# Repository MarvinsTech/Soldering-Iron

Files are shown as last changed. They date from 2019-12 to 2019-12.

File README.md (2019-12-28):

# Soldering-Iron

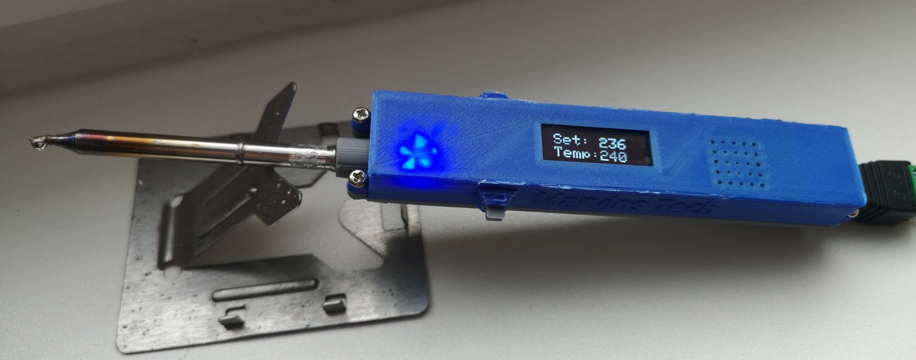
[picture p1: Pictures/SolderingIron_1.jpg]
Soldering Iron

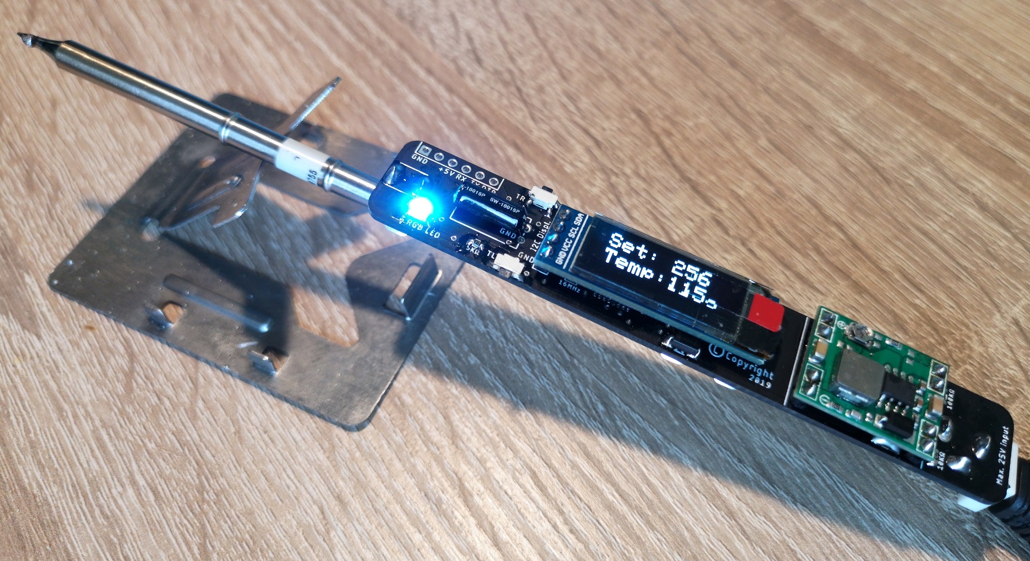
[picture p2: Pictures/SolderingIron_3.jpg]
Soldering Iron


### Required parts
* 1x [Soldering iron PCB](https://github.com/MarvinsTech/Soldering-Iron/tree/master/Eagle%20file/Soldering%20Iron%20V2/GerberFile.zip)
(To order the PCB, visit https://jlcpcb.com)
* 1x [ATmega328pAU](https://de.aliexpress.com/item/32900110997.html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,searchweb201602_4,searchweb201603_53)
* 1x [Female DC power jack](https://de.aliexpress.com/item/1000007253624.html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,searchweb201602_4,searchweb201603_53)
* 1x [16MHz SMD crystal](https://de.aliexpress.com/item/32451311354.html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,searchweb201602_4,searchweb201603_53)
* 1x [SS12 Schottky diode](https://de.aliexpress.com/item/32904408053.html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,searchweb201602_4,searchweb201603_53)
* 1x [2SC3356 R25 SOT-23](https://de.aliexpress.com/item/32895374766.html?spm=a2g0s.9042311.0.0.27424c4daI4iIC)
* 2x [1kΩ SMD Resistor](https://de.aliexpress.com/item/32865947306.html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,searchweb201602_4,searchweb201603_53)
* 5x [10kΩ SMD Resistor](https://de.aliexpress.com/item/32865947306.html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,searchweb201602_4,searchweb201603_53)
* 1x [1MΩ SMD Resistor](https://de.aliexpress.com/item/32865947306.html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,searchweb201602_4,searchweb201603_53)
* 1x [200kΩ SMD Resistor](https://de.aliexpress.com/item/32865947306.html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,searchweb201602_4,searchweb201603_53)
* 2x [5kΩ SMD Resistor](https://de.aliexpress.com/item/32865947306.html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,searchweb201602_4,searchweb201603_53)
* 1x [100KΩ SMD Resistor](https://de.aliexpress.com/item/32865947306.html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,searchweb201602_4,searchweb201603_53)
* 3x [71Ω SMD Resistor](https://de.aliexpress.com/item/32865947306.html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,searchweb201602_4,searchweb201603_53)
* 1x [2,2nF SMD Capacitor](https://de.aliexpress.com/item/33016966236.html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,searchweb201602_4,searchweb201603_53)
* 3x [100nF/0,1uF SMD Capacitor](https://de.aliexpress.com/item/33016966236.html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,searchweb201602_4,searchweb201603_53)
* 3x [PCB Fuse clip](https://de.aliexpress.com/item/32804593991.html?spm=a2g0s.9042311.0.0.27424c4daI4iIC)
* 1x [LM358 LM358DR SOP8](https://de.aliexpress.com/item/32418758151.html?spm=a2g0s.9042311.0.0.27424c4daI4iIC)
* 2x [90° SMD Side push button](https://de.aliexpress.com/item/32876437017.html?spm=a2g0s.9042311.0.0.27424c4daI4iIC)
* 1x [Vibrate sensor SW-18015P](https://de.aliexpress.com/item/32954698373.html?spm=a2g0s.9042311.0.0.27424c4dcR7Mjv)
* 1x [I2C OLED 128x32](https://de.aliexpress.com/item/32794583827.html?spm=a2g0s.9042311.0.0.27424c4dJZC5U3)
* 1x [IRF4905S MOSFET](https://de.aliexpress.com/item/32907696197.html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,searchweb201602_4,searchweb201603_53)
* 1x [RGB LED](https://de.aliexpress.com/item/32384196929.html?spm=a2g0s.9042311.0.0.27424c4dbM3enp)
* 1x USB B cable
* 1x [T12 tip](https://de.aliexpress.com/item/32964816255.html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,searchweb201602_4,searchweb201603_53)
* 1x [Buck converter 22 * 17 * 5mm](https://de.aliexpress.com/item/32901415443.html?spm=a2g0s.9042311.0.0.27424c4dPg1aoU)
* 1x [FTDI module](https://de.aliexpress.com/item/32826575637.html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,searchweb201602_4,searchweb201603_53)
* 1x Heatsink 14 * 14,5 * 4mm
* 4x M2 screws and nuts

### Hints
Note that the two points of the GND bridge are connected with solder!
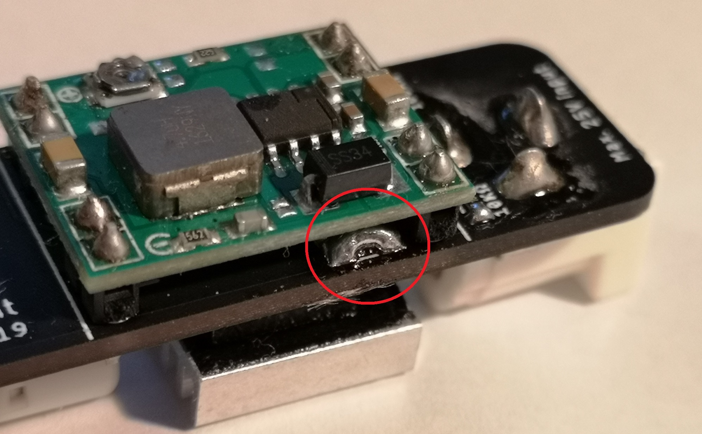
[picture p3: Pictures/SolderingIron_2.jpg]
Soldering iron


### Completely soldered example

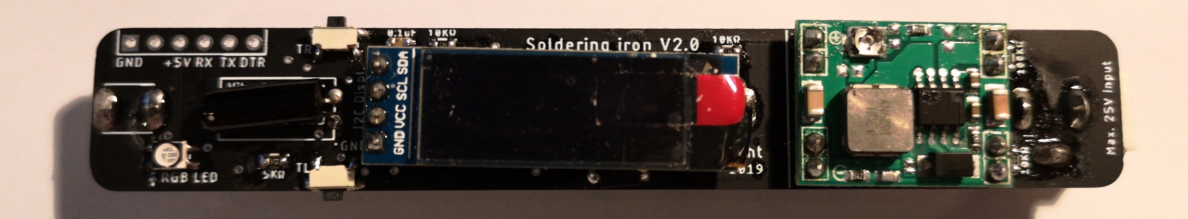
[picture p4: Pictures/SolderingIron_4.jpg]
Soldering iron

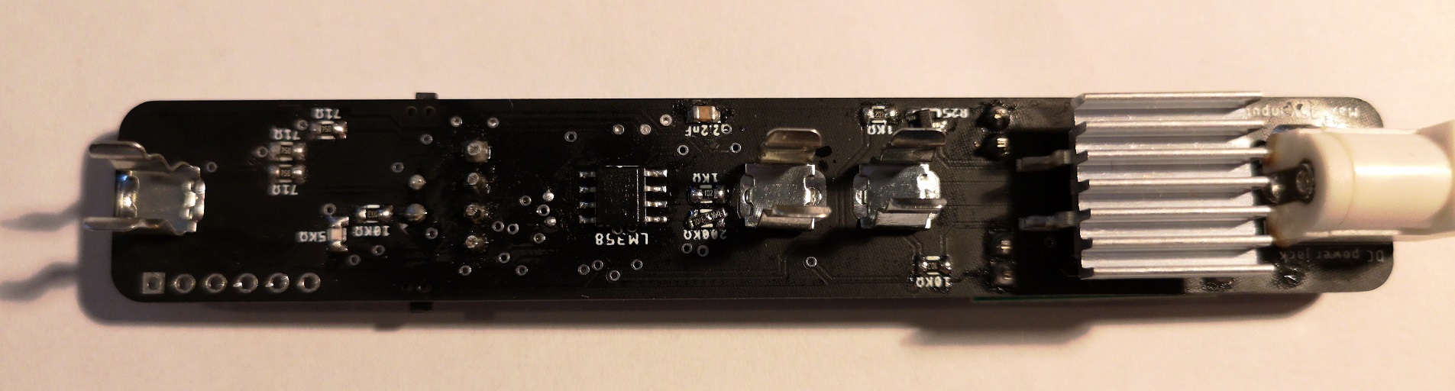
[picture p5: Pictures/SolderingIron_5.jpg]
Soldering iron


### Installing the bootloader on ATmega328
Almost all newly purchased ATmega328 microcontrollers lack the boot loader, so we have to install it ourselves. For this we need an Arduino that is connected as shown in the picture (Make sure that all components on the PCB except the display are soldered!). After the ATmega328 is connected to the Arduino via jumper cables, we have to install OptiLoader on the Arduino and see if it does not display an error message in the serial monitor. If no error message appears, the jumper cables can be unsoldered from the ATmega328.

https://github.com/WestfW/OptiLoader

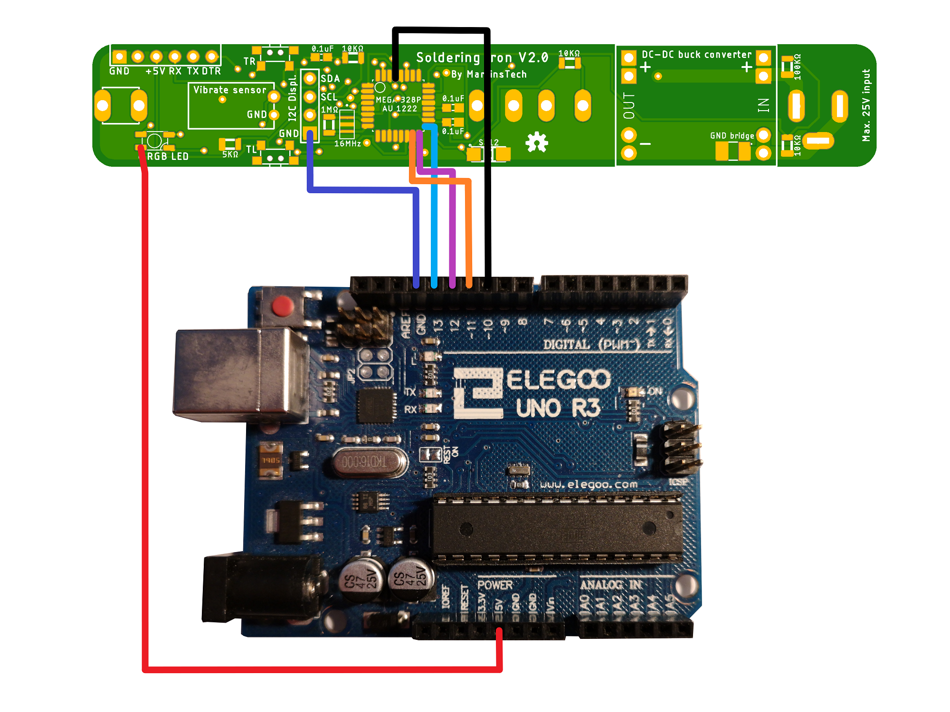
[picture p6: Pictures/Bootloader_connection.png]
Bootloader connection


### Load the program onto ATmega328
Before we load the program onto the ATmega328, we first have to implement the FTDI module in the Arduino IDE. To do this, follow the step-by-step instructions below.

* Open the Arduino IDE.
* Open the File > Preferences menu item.
* Enter the following URL in Additional Boards Manager URLs:
`https://mcudude.github.io/MiniCore/package_MCUdude_MiniCore_index.json`
* Open the Tools > Board > Boards Manager... menu item.
* Wait for the platform indexes to finish downloading.
* Scroll down until you see the MiniCore entry and click on it.
* Click Install.

Next we select the ATmega328 board from Tools, connect the FTDI module to the computer and upload the program to the PCB via the FTDI interface.

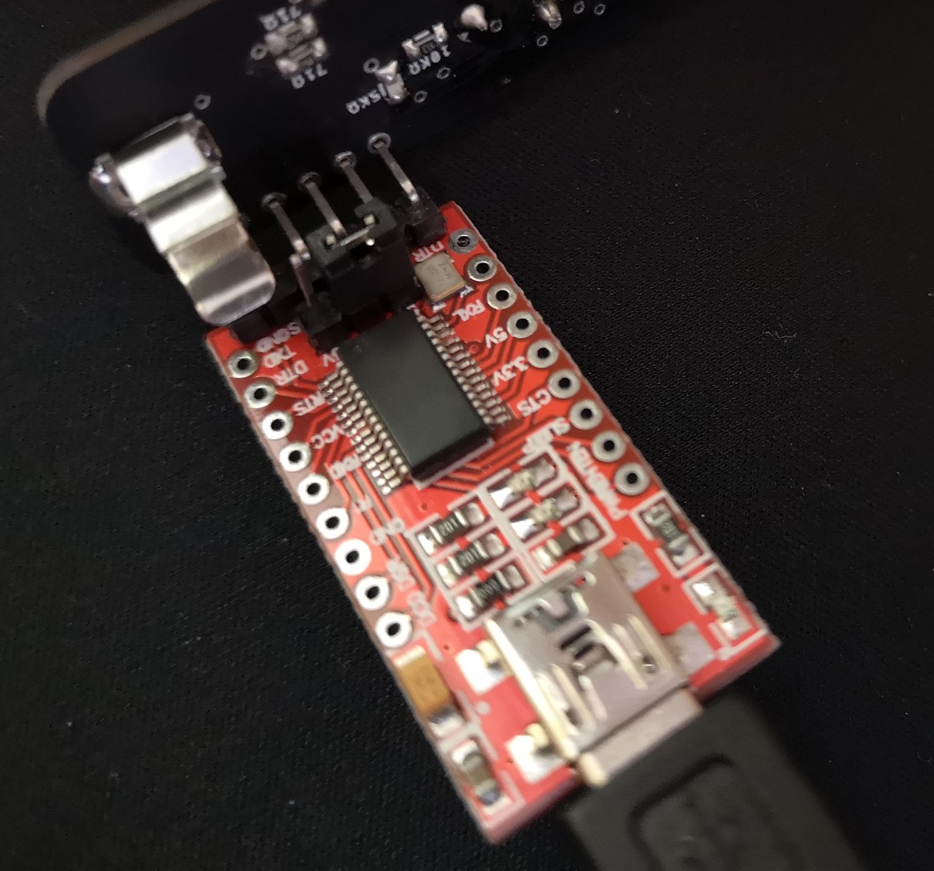
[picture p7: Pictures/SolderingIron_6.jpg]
FTDI programmer


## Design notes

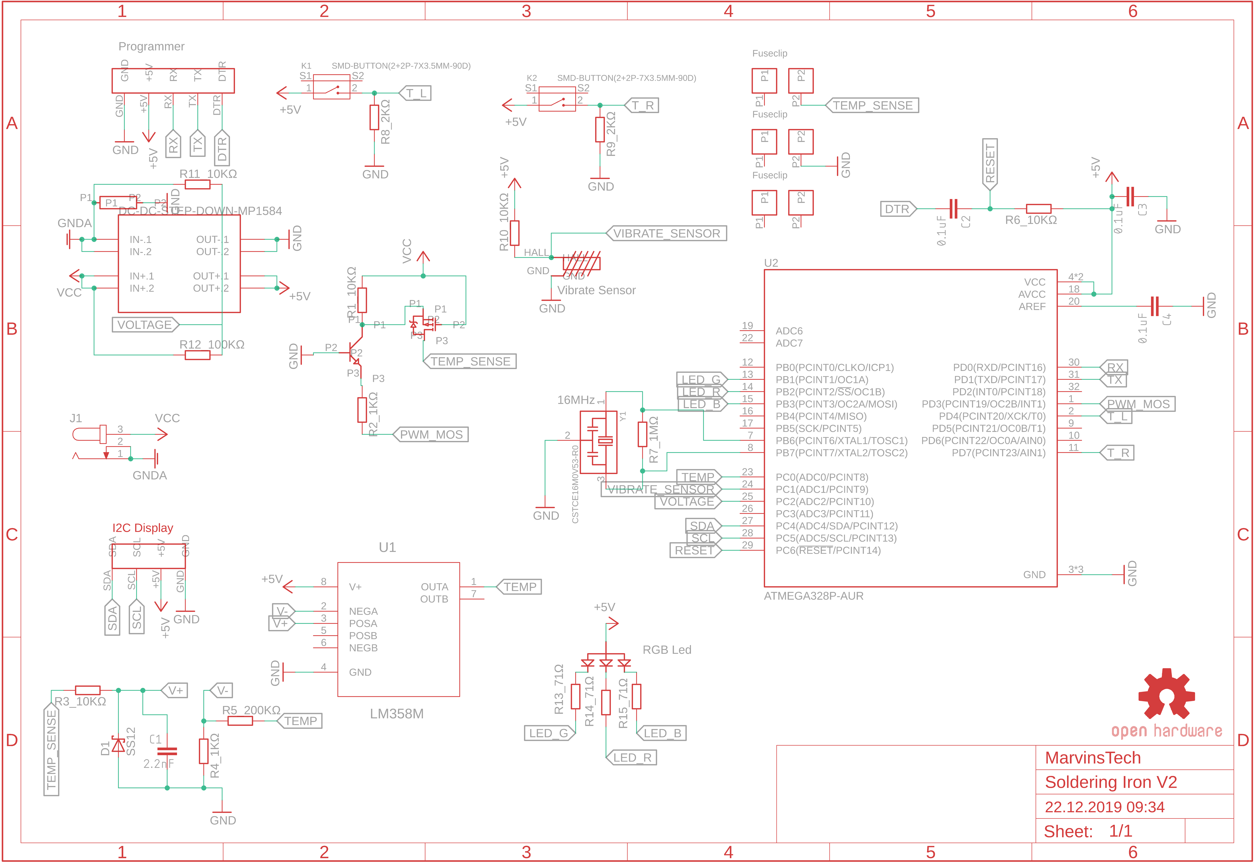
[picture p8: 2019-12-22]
Eagle file/Soldering Iron V2/Schematic.png

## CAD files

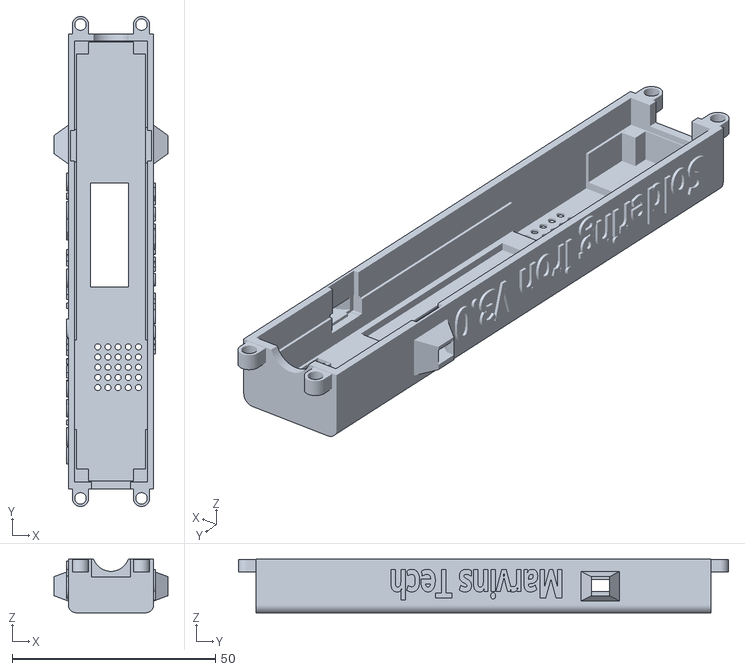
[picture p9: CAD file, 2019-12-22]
3D case/1x Soldering Iron V2.0 top.stl
28.0 x 120.5 x 13.2

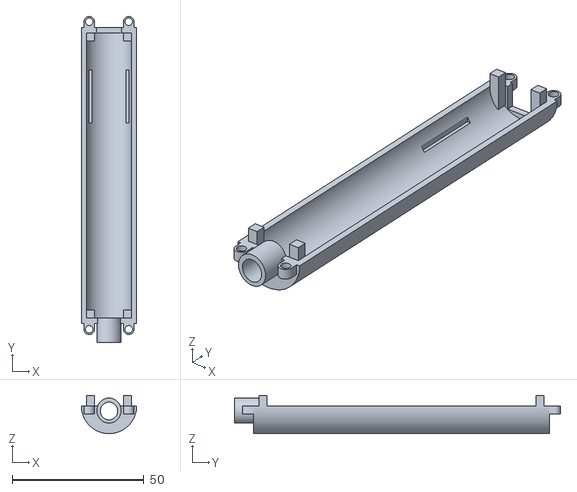
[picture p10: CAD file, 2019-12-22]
3D case/1x Soldering Iron V2.0 bottom.stl
21.0 x 123.5 x 14.5

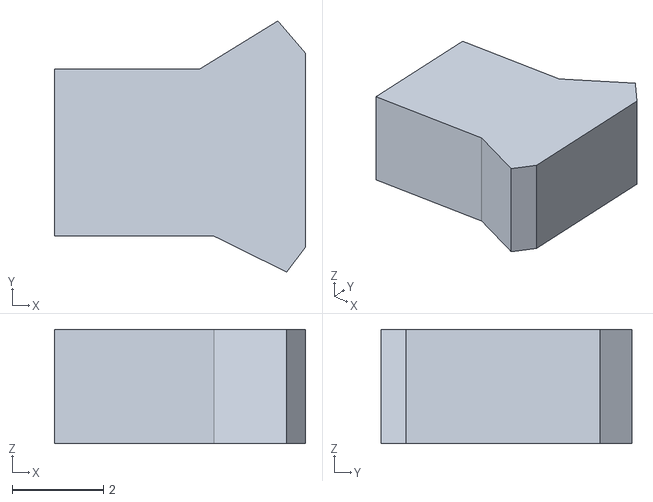
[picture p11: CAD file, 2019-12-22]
3D case/2x Soldering Iron V2.0 button.stl
5.50 x 5.50 x 2.50

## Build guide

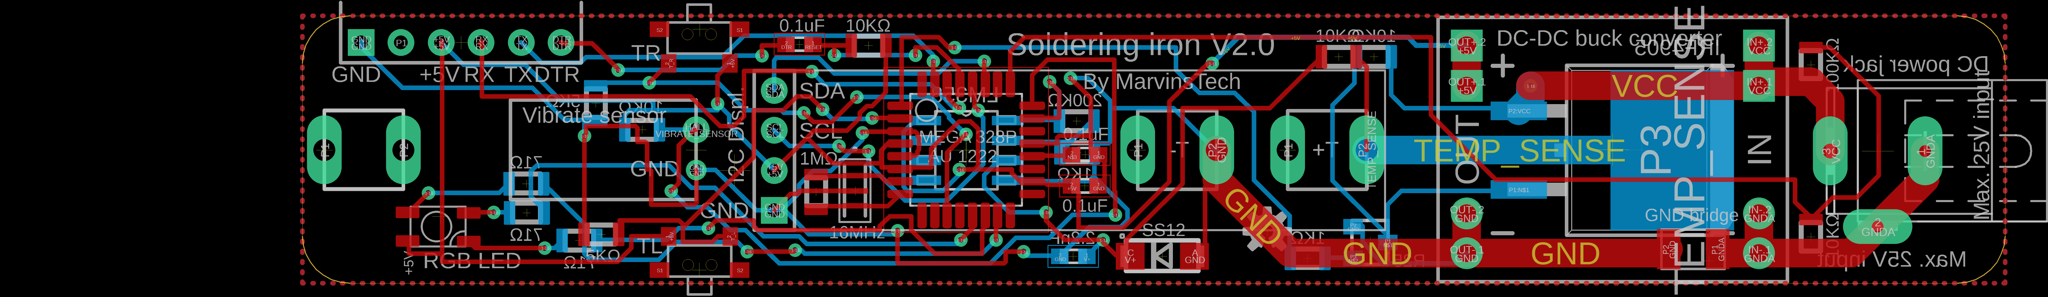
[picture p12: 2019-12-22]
Eagle file/Soldering Iron V2/SolderingIronV2.png

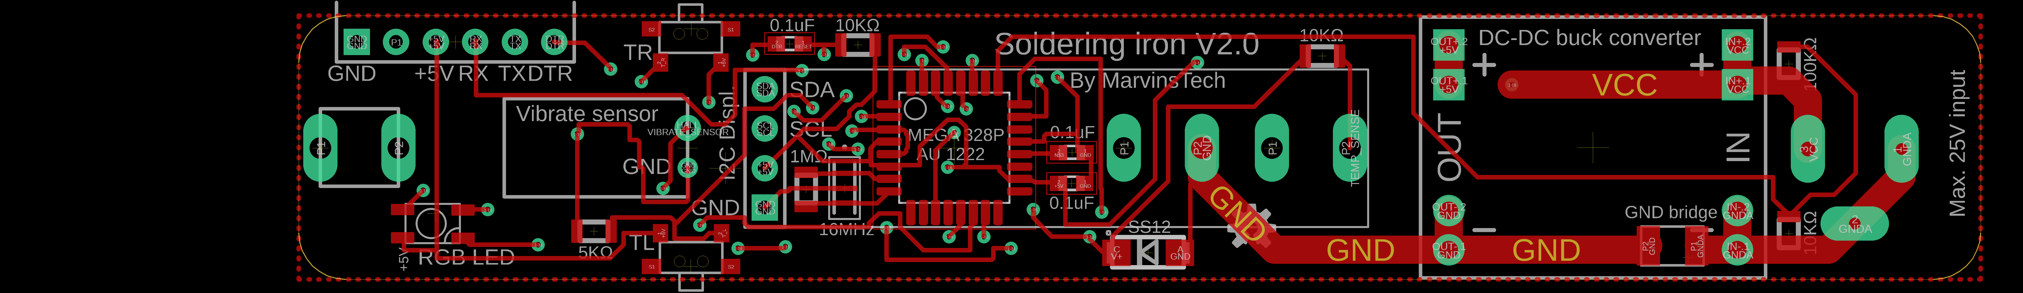
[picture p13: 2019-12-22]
Eagle file/Soldering Iron V2/SolderingIronV2_top.png

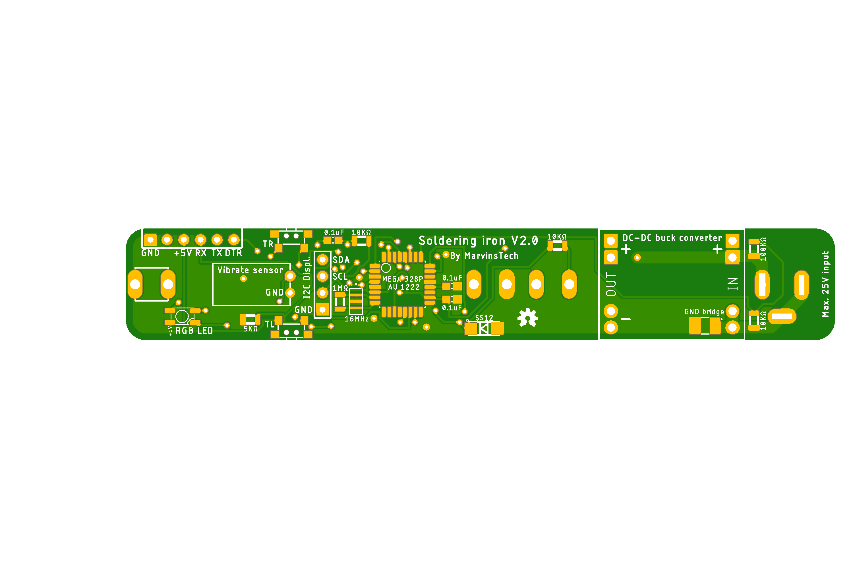
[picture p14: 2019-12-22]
Eagle file/Soldering Iron V2/Soldering Iron V2.png

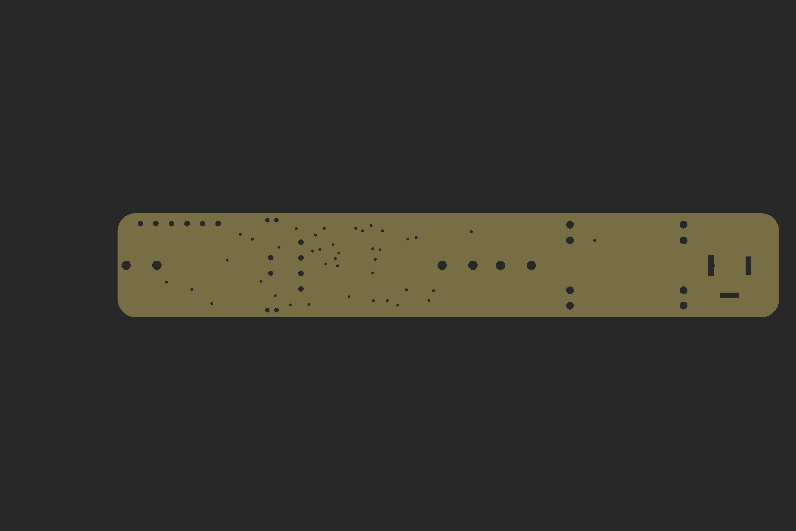
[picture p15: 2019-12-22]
Eagle file/Soldering Iron V2/Soldering Iron V2_drills.png

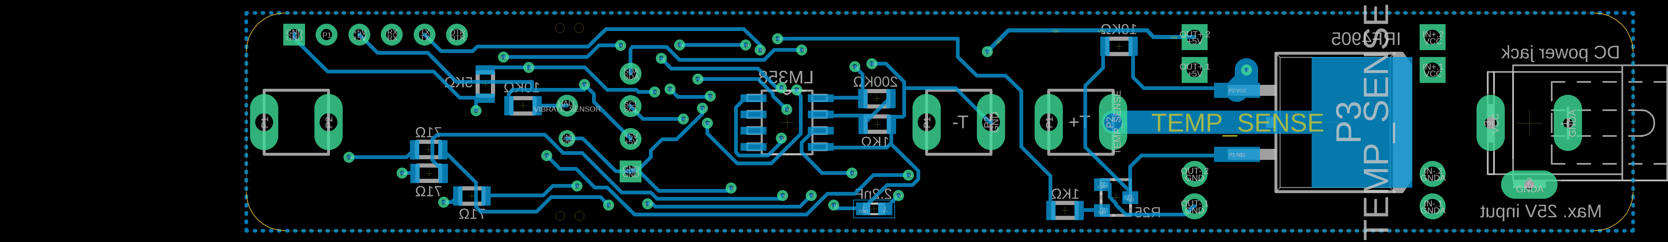
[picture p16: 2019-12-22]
Eagle file/Soldering Iron V2/SolderingIronV2_bottom.png

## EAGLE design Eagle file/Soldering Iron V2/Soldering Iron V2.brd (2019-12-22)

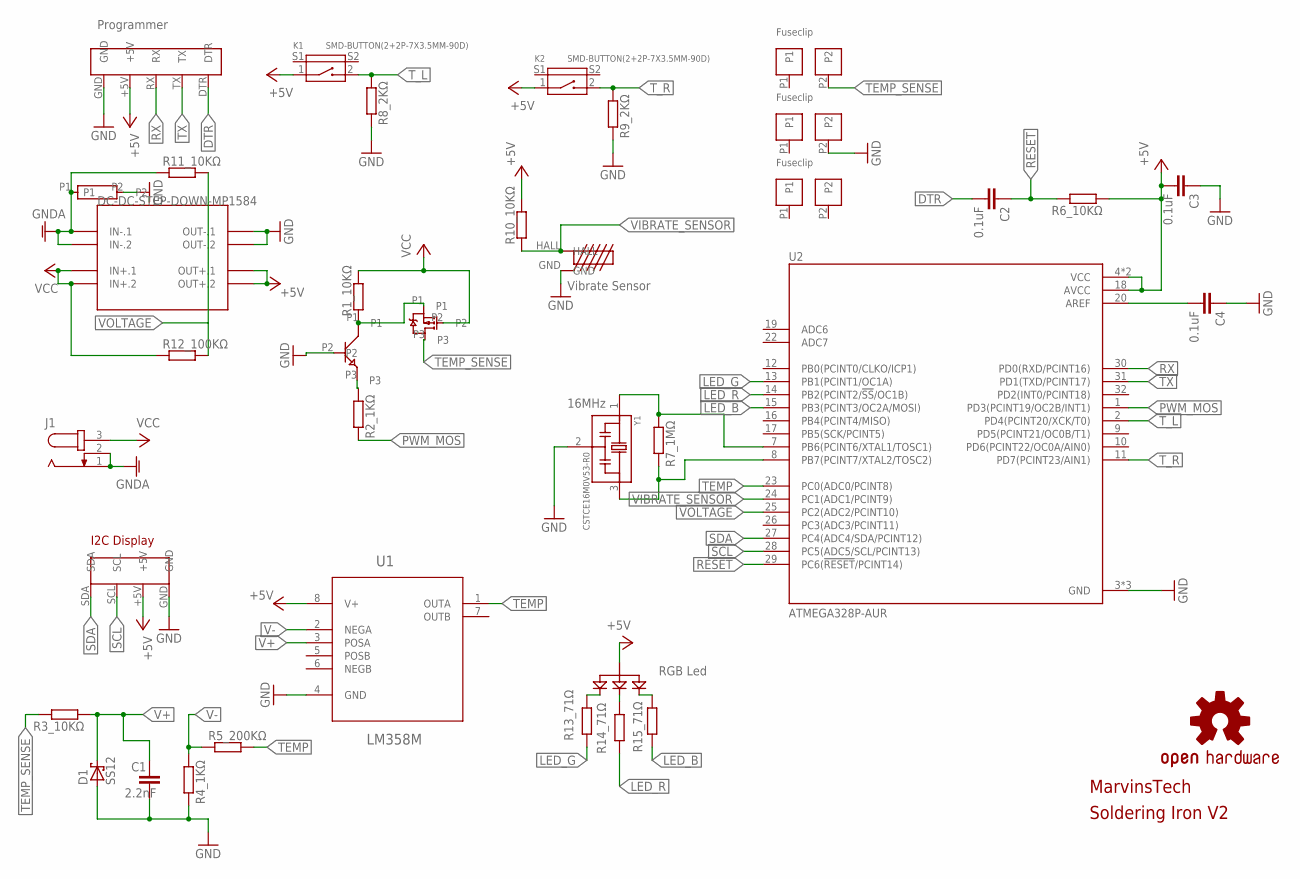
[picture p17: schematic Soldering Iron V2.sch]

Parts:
C1: 2.2nF; 0603
C2, C3, C4: 0.1uF; 0603
D1: SS12; DO214AC
J1: JACK-PLUG0; SPC4077
K1, K2: SMD-BUTTON(2+2P-7X3.5MM-90D); SW4-SMD-7.0X3.5X3.5MM-90D
R1_10KΩ, R2_1KΩ, R3_10KΩ, R4_1KΩ, R5_200KΩ, R6_10KΩ, R7_1MΩ, R8_2KΩ, R9_2KΩ, R10_10KΩ, R11_10KΩ, R12_100KΩ, R13_71Ω, R14_71Ω, R15_71Ω: SMK
U1: LM358M; SOIC127P620X175-8N
U2: ATMEGA328P-AUR; QFP80P900X900X120-32N
U$1: DC-DC-STEP-DOWN-MP1584
U$2: IRF4905STRLPBF; D2PAK-5
U$3: 2SC3356NPNBJT; TO236
U$4: I2C_DISPLAY
U$5: VIBRATESENSOR
U$6, U$7, U$8: FUSECLIPS; FUSECLIP
U$9: SHUNT_RESISTOR1; RESISTOR1
U$10: RGBLED
U$11: PROGRAMMER
U$15: OSHW-LOGOS; OSHW-LOGO-S
Y1: CSTCE16M0V53-R0; OSC_CSTCE16M0V53-R0

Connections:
+5V: C3.2, K1.1, K2.1, R6_10KΩ.2, R10_10KΩ.1, U1.8 (V+), U2.4 (VCC), U2.6 (VCC), U2.18 (AVCC), U$1.OUT+.1, U$1.OUT+.2, U$4.+5V, U$10.+5V, U$11.+5V
DTR: C2.2, U$11.DTR
GND: C1.2, C3.1, C4.1, D1.A, R4_1KΩ.1, R8_2KΩ.1, R9_2KΩ.1, U1.4 (GND), U2.3 (GND), U2.5 (GND), U2.21 (GND), U$1.OUT-.1, U$1.OUT-.2, U$3.P2, U$4.GND, U$5.GND, U$7.P2, U$9.P2, U$11.GND, Y1.2
GNDA: J1.1, J1.2, R11_10KΩ.2, U$1.IN-.1, U$1.IN-.2, U$9.P1
LED_B: R15_71Ω.1, U2.15 (PB3(PCINT3/OC2A/MOSI))
LED_G: R13_71Ω.2, U2.13 (PB1(PCINT1/OC1A))
LED_R: R14_71Ω.2, U2.14 (PB2(PCINT2/!SS!/OC1B))
unnamed: R1_10KΩ.2, U$2.P1, U$3.P1
unnamed: R2_1KΩ.2, U$3.P3
unnamed: C4.2, U2.20 (AREF)
unnamed: R7_1MΩ.2, U2.7 (PB6(PCINT6/XTAL1/TOSC1)), Y1.1
unnamed: R7_1MΩ.1, U2.8 (PB7(PCINT7/XTAL2/TOSC2)), Y1.3
unnamed: R14_71Ω.1, U$10.P2
unnamed: R13_71Ω.1, U$10.P3
unnamed: R15_71Ω.2, U$10.P1
PWM_MOS: R2_1KΩ.1, U2.1 (PD3(PCINT19/OC2B/INT1))
RESET: C2.1, R6_10KΩ.1, U2.29 (PC6(!RESET!/PCINT14))
RX: U2.30 (PD0(RXD/PCINT16)), U$11.RX
SCL: U2.28 (PC5(ADC5/SCL/PCINT13)), U$4.SCL
SDA: U2.27 (PC4(ADC4/SDA/PCINT12)), U$4.SDA
TEMP: R5_200KΩ.1, U1.1 (OUTA), U2.23 (PC0(ADC0/PCINT8))
TEMP_SENSE: R3_10KΩ.1, U$2.P3, U$6.P2
TX: U2.31 (PD1(TXD/PCINT17)), U$11.TX
T_L: K1.2, R8_2KΩ.2, U2.2 (PD4(PCINT20/XCK/T0))
T_R: K2.2, R9_2KΩ.2, U2.11 (PD7(PCINT23/AIN1))
V+: C1.1, D1.C, R3_10KΩ.2, U1.3 (POSA)
V-: R4_1KΩ.2, R5_200KΩ.2, U1.2 (NEGA)
VCC: J1.3, R1_10KΩ.1, R12_100KΩ.2, U$1.IN+.1, U$1.IN+.2, U$2.P2
VIBRATE_SENSOR: R10_10KΩ.2, U2.24 (PC1(ADC1/PCINT9)), U$5.HALL
VOLTAGE: R11_10KΩ.1, R12_100KΩ.1, U2.25 (PC2(ADC2/PCINT10))

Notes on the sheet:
16MHz
Vibrate Sensor
Programmer
RGB Led
MarvinsTech
Soldering Iron V2

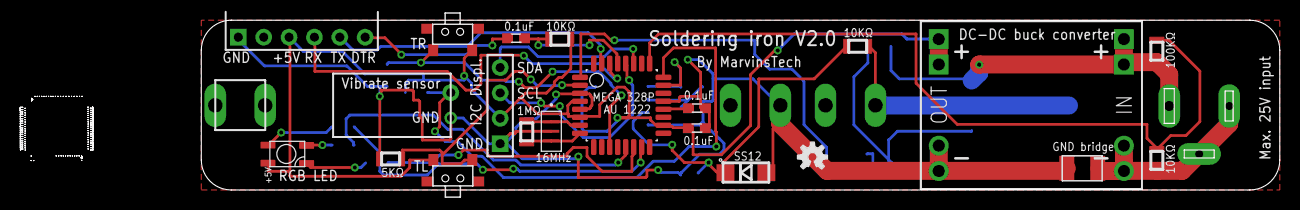
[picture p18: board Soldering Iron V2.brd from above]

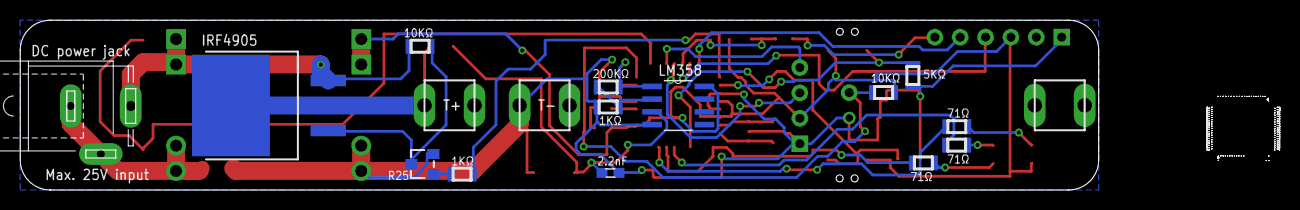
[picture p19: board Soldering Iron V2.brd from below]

Board: 2 copper layers, 108.0 x 17.0 mm, 38 parts (14 on the bottom side), 30 nets.

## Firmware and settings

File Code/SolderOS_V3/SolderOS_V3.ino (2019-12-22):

/*SolderOS V3.0 | Changed on 22/12/2019 by MarvinsTech
*/

static const unsigned char PROGMEM  press_logo[] =
{
  B00000000, B00000000, B00000000, B00000000, B00000000, B00000000, B00000000, B00000000, B00000000, B00000000, B00000000, B00000000, B00000000, B00000000, B00000000, B00000000,
  B11111001, B11110011, B11100111, B10001111, B10000000, B00000000, B00000000, B00000000, B00000000, B00000000, B00000000, B00000000, B00000000, B00000000, B00000000, B00000000,
  B10000000, B01000010, B00100100, B01000010, B00000000, B00000000, B00000000, B00000000, B00000000, B00000000, B00000000, B00000000, B00000000, B00000000, B00000000, B00000000,
  B10000000, B01000010, B00100100, B01000010, B00000000, B00000000, B00000000, B00000000, B00000000, B00000000, B00000000, B00000000, B00000000, B00000000, B00000000, B00000000,
  B11111000, B01000011, B11100111, B10000010, B00111111, B11111111, B11111111, B11111111, B11111100, B00000000, B00000000, B00000000, B00000000, B00000000, B00000000, B00000000,
  B00001000, B01000010, B00100101, B00000010, B00000000, B00000000, B00000000, B00000000, B00000010, B00000000, B00000000, B00000000, B00000000, B00000000, B00000000, B00000000,
  B00001000, B01000010, B00100100, B10000010, B00000000, B00000000, B00000000, B00000000, B00000001, B00000000, B00000000, B00000000, B00000000, B00000000, B00000000, B00000000,
  B11111000, B01000010, B00100100, B01000010, B00000000, B00000000, B00000000, B00000000, B00000000, B10000000, B00000000, B00000000, B00000000, B00000000, B00000000, B00000000,
  B00000000, B00000000, B00000000, B00000000, B00000000, B00000000, B00000000, B00000000, B00000000, B00000000, B00000000, B00000000, B00000000, B00000000, B00000000, B00000000,
  B00000000, B00000000, B00000000, B00000000, B00000000, B00000000, B00000000, B00000000, B00000000, B11000000, B11000000, B00000000, B00000000, B00000000, B00000000, B00000000,
  B00000000, B00000000, B00000000, B00000000, B00000000, B00000000, B00000000, B00000000, B00000000, B01100001, B10000000, B00000000, B00000000, B00000000, B00000000, B00000000,
  B00000000, B00000000, B00000000, B00000000, B00000000, B00000000, B00000000, B00000000, B00000000, B00111111, B00000000, B00000000, B00000000, B00000000, B00000000, B00000000,
  B00000000, B00000000, B00000000, B00000000, B00000000, B00000000, B00000000, B00000000, B00000000, B00001100, B00000000, B00000000, B00000000, B00000000, B00000000, B00000000,
  B00000000, B00000000, B00000000, B00000000, B00000000, B00000000, B00000000, B00000000, B00000000, B00000000, B00000000, B00000000, B00000000, B00000000, B00000000, B00000000,
  B00000000, B00000000, B00000000, B00000000, B00000000, B00000000, B00000000, B00000000, B00000000, B00111110, B00000000, B00000000, B00000000, B00000000, B00011111, B00000000,
  B00000000, B00000000, B00000000, B00000000, B00000000, B00000000, B00000000, B00000000, B11111111, B11111111, B11111111, B11111111, B11111111, B11111111, B11111111, B11100000,
  B00000000, B00000000, B00111111, B11111111, B11111111, B11111111, B11111111, B11111111, B11111111, B11111111, B11111111, B11111111, B11111111, B11111111, B11111111, B11111111,
  B00000000, B00000001, B11111111, B11111111, B11111111, B11111111, B11111111, B11111111, B11111111, B11111111, B11111111, B11111111, B11111111, B11111111, B11111111, B11111111,
  B00000000, B00000000, B00111111, B11111111, B11111111, B11111111, B11111111, B11111111, B11111111, B11111111, B11111111, B11111111, B11111111, B11111111, B11111111, B11100000,
  B00000000, B00000000, B00000000, B00000000, B00000000, B00000000, B00000000, B00000000, B11111111, B11111111, B11111111, B11111111, B11111111, B11111111, B11111111, B11100000,
  B00000000, B00000000, B00000000, B00000000, B00000000, B00000000, B00000000, B00000000, B00000000, B00111110, B00000000, B00000000, B00000000, B00000000, B00000000, B00000000,
  B00000000, B00000000, B00000000, B00000000, B00000000, B00000000, B00000000, B00000000, B00000000, B00000000, B00000000, B00000000, B00000000, B00000000, B00000000, B00000000,
  B00000000, B00000000, B00000000, B00000000, B00000000, B00000000, B00000000, B00000000, B00000000, B00000000, B00000000, B00000000, B00000000, B00000000, B00000000, B00000000,
  B00000000, B00000000, B00000000, B00000000, B00000000, B00000000, B00000000, B00000000, B00000000, B00000000, B00000000, B00000000, B00000000, B00000000, B00000000, B00000000,
  B00000000, B00000000, B00000000, B00000000, B00000000, B00000000, B00000000, B00000000, B00000000, B00000000, B00000000, B00000000, B00000000, B00000000, B00000000, B00000000,
  B00000000, B00000000, B00000000, B00000000, B00000000, B00000000, B00000000, B00000000, B00000000, B00000000, B00000000, B00000000, B00000000, B00000000, B00000000, B00000000,
  B00000000, B00000000, B00000000, B00000000, B00000000, B00000000, B00000000, B00000000, B00000000, B00000000, B00000000, B00000000, B00000000, B00000000, B00000000, B00000000,
  B00000000, B00000000, B00000000, B00000000, B00000000, B00000000, B00000000, B00000000, B00000000, B00000000, B00000000, B00000000, B00000000, B00000000, B00000000, B00000000,
  B00000000, B00000000, B00000000, B00000000, B00000000, B00000000, B00000000, B00000000, B00000000, B00000000, B00000000, B00000000, B00000000, B00000000, B00000000, B00000000,
  B00000000, B00000000, B00000000, B00000000, B00000000, B00000000, B00000000, B00000000, B00000000, B00000000, B00000000, B00000000, B00000000, B00000000, B00000000, B00000000,
  B00000000, B00000000, B00000000, B00000000, B00000000, B00000000, B00000000, B00000000, B00000000, B00000000, B00000000, B00000000, B00000000, B00000000, B00000000, B00000000,
  B00000000, B00000000, B00000000, B00000000, B00000000, B00000000, B00000000, B00000000, B00000000, B00000000, B00000000, B00000000, B00000000, B00000000, B00000000, B00000000
};

//Bytes for the sleep mode icon toggle with CONFIG icon
static const unsigned char PROGMEM no_press_logo[] =
{
  B00000000, B00000000, B00000000, B00000000, B00000000, B00000000, B00000000, B00000000, B00000000, B00000000, B00000000, B00000000, B00000000, B00000000, B00000000, B00000000,
  B00000000, B00000000, B00000000, B00000000, B00000000, B00000000, B00000000, B00000000, B00000000, B00000000, B00000000, B00000000, B00000000, B00000000, B00000000, B00000000,
  B00000000, B00000000, B00000000, B00000000, B00000000, B00000000, B00000000, B00000000, B00000000, B00000000, B00000000, B00000000, B00000000, B00000000, B00000000, B00000000,
  B00000000, B00000000, B00000000, B00000000, B00000000, B00000000, B00000000, B00000000, B00000000, B00000000, B00000000, B00000000, B00000000, B00000000, B00000000, B00000000,
  B00000000, B00000000, B00000000, B00000000, B00000000, B00000000, B00000000, B00000000, B00000000, B00000000, B00000000, B00000000, B00000000, B00000000, B00000000, B00000000,
  B00000000, B00000000, B00000000, B00000000, B00000000, B00000000, B00000000, B00000000, B00000000, B00000000, B00000000, B00000000, B00000000, B00000000, B00000000, B00000000,
  B00000000, B00000000, B00000000, B00000000, B00000000, B00000000, B00000000, B00000000, B00000000, B00000000, B00000000, B00000000, B00000000, B00000000, B00000000, B00000000,
  B00000000, B00000000, B00000000, B00000000, B00000000, B00000000, B00000000, B00000000, B00000000, B00000000, B00000000, B00000000, B00000000, B00000000, B00000000, B00000000,
  B00000000, B00000000, B00000000, B00000000, B00000000, B00000000, B00000000, B00000000, B00000000, B00000000, B00000000, B00000000, B00000000, B00000000, B00000000, B00000000,
  B00000000, B00000000, B00000000, B00000000, B00000000, B00000000, B00000000, B00000000, B00000000, B00000000, B00000000, B00000000, B00000000, B00000000, B00000000, B00000000,
  B00000000, B00000000, B00000000, B00000000, B00000000, B00000000, B00000000, B00000000, B00000000, B00000000, B00000000, B00000000, B00000000, B00000000, B00000000, B00000000,
  B00000000, B00000000, B00000000, B00000000, B00000000, B00000000, B00000000, B00000000, B00000000, B00000000, B00000000, B00000000, B00000000, B00000000, B00000000, B00000000,
  B00000000, B00000000, B00000000, B00000000, B00000000, B00000000, B00000000, B00000000, B00000000, B00000000, B00000000, B00000000, B00000000, B00000000, B00000000, B00000000,
  B00000000, B00000000, B00000000, B00000000, B00000000, B00000000, B00000000, B00000000, B00000000, B00000000, B00000000, B00000000, B00000000, B00000000, B00000000, B00000000,
  B00000000, B00000000, B00000000, B00000000, B00000000, B00000000, B00000000, B00000000, B00000000, B00111110, B00000000, B00000000, B00000000, B00000000, B00011111, B00000000,
  B00000000, B00000000, B00000000, B00000000, B00000000, B00000000, B00000000, B00000000, B11111111, B11111111, B11111111, B11111111, B11111111, B11111111, B11111111, B11100000,
  B00000000, B00000000, B00111111, B11111111, B11111111, B11111111, B11111111, B11111111, B11111111, B11111111, B11111111, B11111111, B11111111, B11111111, B11111111, B11111111,
  B00000000, B00000001, B11111111, B11111111, B11111111, B11111111, B11111111, B11111111, B11111111, B11111111, B11111111, B11111111, B11111111, B11111111, B11111111, B11111111,
  B00000000, B00000000, B00111111, B11111111, B11111111, B11111111, B11111111, B11111111, B11111111, B11111111, B11111111, B11111111, B11111111, B11111111, B11111111, B11100000,
  B00000000, B00000000, B00000000, B00000000, B00000000, B00000000, B00000000, B00000000, B11111111, B11111111, B11111111, B11111111, B11111111, B11111111, B11111111, B11100000,
  B00000000, B00000000, B00000000, B00000000, B00000000, B00000000, B00000000, B00000000, B00000000, B00111110, B00000000, B00000000, B00000000, B00000000, B00000000, B00000000,
  B00000000, B00000000, B00000000, B00000000, B00000000, B00000000, B00000000, B00000000, B00000000, B00000000, B00000000, B00000000, B00000000, B00000000, B00000000, B00000000,
  B00000000, B00000000, B00000000, B00000000, B00000000, B00000000, B00000000, B00000000, B00000000, B00001100, B00000000, B00000000, B00000000, B00000000, B00000000, B00000000,
  B00000000, B00000000, B00000000, B00000000, B00000000, B00000000, B00000000, B00000000, B00000000, B00111111, B00000000, B00000000, B00000000, B00000000, B00000000, B00000000,
  B11111001, B11110010, B00100111, B11001001, B11110000, B00000000, B00000000, B00000000, B00000000, B01100001, B10000000, B00000000, B00000000, B00000000, B00000000, B00000000,
  B10000001, B00010011, B00100100, B00001001, B00000000, B00000000, B00000000, B00000000, B00000000, B11000000, B11000000, B00000000, B00000000, B00000000, B00000000, B00000000,
  B10000001, B00010011, B00100111, B10001001, B00000000, B00000000, B00000000, B00000000, B00000000, B10000000, B00000000, B00000000, B00000000, B00000000, B00000000, B00000000,
  B10000001, B00010010, B10100100, B00001001, B00000000, B00000000, B00000000, B00000000, B00000001, B00000000, B00000000, B00000000, B00000000, B00000000, B00000000, B00000000,
  B10000001, B00010010, B01100100, B00001001, B00110011, B11111111, B11111111, B11111111, B11111110, B00000000, B00000000, B00000000, B00000000, B00000000, B00000000, B00000000,
  B10000001, B00010010, B01100100, B00001001, B00010000, B00000000, B00000000, B00000000, B00000000, B00000000, B00000000, B00000000, B00000000, B00000000, B00000000, B00000000,
  B11111001, B11110010, B00100100, B00001001, B11110000, B00000000, B00000000, B00000000, B00000000, B00000000, B00000000, B00000000, B00000000, B00000000, B00000000, B00000000,
  B00000000, B00000000, B00000000, B00000000, B00000000, B00000000, B00000000, B00000000, B00000000, B00000000, B00000000, B00000000, B00000000, B00000000, B00000000, B00000000
};

String Version = "Version 3.0";
float min_temp = 150;                            //This is the minimum temperature that the iron could get
float max_temp = 500;                            //This is the maximum temperature that the iron could get
float Delay = 200;                               //Refresh rate. This is the time in ms the loop runs (PID+temperature read)
int   setpoint = 250;                            //Temperature setpoint initial value
int   sleeptime = 3;                             //Wait to enter into sleep mode. Time in minutes
int   max_sleeptime = 10;                        //This is the maximum sleep time you could set the iron
int   sleeptime_adress = 2;
int   setpoint_adress_low = 3;
int   setpoint_adress_mid = 4;
int   setpoint_adress_high = 5;

float Voltage = 0.0;
int val = 0;

#include "max6675.h"              //Downlaod it here: https://github.com/adafruit/MAX6675-library
#include <SPI.h>
#include <Wire.h>
#include <Adafruit_GFX.h>         //Downlaod it here: https://github.com/adafruit/Adafruit-GFX-Library
#include <Adafruit_SSD1306.h>     //Downlaod it here: https://github.com/adafruit/Adafruit_SSD1306
#include <FastPID.h>              //Dwonload it here: https://github.com/mike-matera/FastPID
#include <EEPROM.h>
#include <math.h>
#include "pins.h"

#define OLED_RESET 8
Adafruit_SSD1306 display(OLED_RESET);
#define NUMFLAKES 5
#define XPOS 0
#define YPOS 1
#define DELTAY 2
#if (SSD1306_LCDHEIGHT != 32)
#error("Height incorrect, please fix Adafruit_SSD1306.h!");
#endif
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
void loop() {
  MeasureVoltage();

  if (sleeptime == 0) {
    sleep_enabeled = false;
  }

  sleep_time_detect = sleeptime * 60000;
  currentMillis = millis(); 

  if ((currentMillis - previousMillis >= Delay) &&  (!sleepmode && !temp_change && !sleepmode_VibrSensor)) {
    previousMillis += Delay;
    digitalWrite(MOSFED, LOW);         
    delayMicroseconds(300);               
    temperature_read = read_temperature();  

    uint32_t before, after;
    before = micros();
    uint8_t output = myPID.step(setpoint, temperature_read);
    after = micros();

    analogWrite(MOSFED, output);

    temp_to_print = map_temp_to_print(temperature_read);

    if ((temp_to_print < 500) && (var1 < 3)) {
      display.clearDisplay();
      display.setTextSize(2);
      display.setTextColor(WHITE);
      display.setCursor(10, 0);
      display.print("Set: ");
      display.setCursor(70, 0);
      display.print(setpoint, 1);
      display.setCursor(10, 18);
      display.print("Temp: ");
      display.setCursor(70, 18);
      display.print(temp_to_print, 1);
      display.display();
    }
    if (temp_to_print > 500) {
      display.clearDisplay();
      display.setTextSize(2);
      display.setTextColor(WHITE);
      display.setCursor(10, 0);
      display.print("Set: ");
      display.setCursor(70, 0);
      display.print(setpoint, 1);
      display.setCursor(10, 18);
      display.print("Tip ERROR");
      display.display();
      digitalWrite(LED_R, HIGH);
      digitalWrite(LED_G, HIGH);
      digitalWrite(LED_B, HIGH);
    }
    LedTemperature();
  }

  if ((digitalRead(ButtonR)) &&  (sleepmode || sleepmode_VibrSensor) && settings == 0) {
    digitalWrite(LED_R, HIGH);
    digitalWrite(LED_G, HIGH);
    digitalWrite(LED_B, HIGH);
    previousMillis_sleep = currentMillis;
    if (sleep_out_count > 800) {
      analogWrite(Buzzer, 200);
      delay(70);
      analogWrite(Buzzer, LOW);
      sleepmode = false;
      sleepmode_VibrSensor = false;
      sleepmode_VibrSensor = false;
      sleep_out_count = 0;
      delay(100);
    }
    sleep_out_count = sleep_out_count + 1;
  }

  if (digitalRead(ButtonR)  &&  !digitalRead(ButtonL) && !sleepmode  && !sleepmode_VibrSensor) {
    digitalWrite(LED_R, HIGH);
    digitalWrite(LED_G, HIGH);
    digitalWrite(LED_B, HIGH);
    previousMillis_sleep = currentMillis;

    if (sleep_out_count > 1000) {
      digitalWrite(MOSFED, LOW);
      setpoint = setpoint + 10;
      slide_set_temp_down(setpoint);
      temp_change = true;
      sleep_out_count = 0;
      if (setpoint > max_temp) {
        setpoint = max_temp;
      }
      display.clearDisplay();
      display.setTextSize(3);
      display.setTextColor(WHITE);
      display.setCursor(35, 4);
      display.print(setpoint);
      display.display();
    }
    sleep_out_count = sleep_out_count + 1;
  }

  if (!digitalRead(ButtonR)  && digitalRead(ButtonL) && !sleepmode && !sleepmode_VibrSensor) {
    digitalWrite(LED_R, HIGH);
    digitalWrite(LED_G, HIGH);
    digitalWrite(LED_B, HIGH);
    previousMillis_sleep = currentMillis;

    if (sleep_out_count > 1000) {
      digitalWrite(MOSFED, LOW);
      setpoint = setpoint - 10;
      slide_set_temp_up(setpoint);
      temp_change = true;
      sleep_out_count = 0;

      if (setpoint < min_temp) {
        setpoint = min_temp;
      }
      display.clearDisplay();
      display.setTextSize(3);
      display.setTextColor(WHITE);
      display.setCursor(35, 4);
      display.print(setpoint);
      display.display();
    }
    sleep_out_count = sleep_out_count + 1;
  }

  if (!digitalRead(ButtonR) && !digitalRead(ButtonL) && temp_change) {
    digitalWrite(LED_R, HIGH);
    digitalWrite(LED_G, HIGH);
    digitalWrite(LED_B, HIGH);
    if (temp_change_count > 15000) {
      temp_change = false;
      temp_change_count = 0;
      set_temp_made = false;
      previousMillis_sleep = currentMillis;
    }
    temp_change_count = temp_change_count + 1;
  }

  if (digitalRead(ButtonR) && digitalRead(ButtonL) && !sleepmode) {
    digitalWrite(LED_R, HIGH);
    digitalWrite(LED_G, HIGH);
    digitalWrite(LED_B, HIGH);
    if (both_pressed_count > 5000) {
      analogWrite(Buzzer, 200);
      delay(70);
      analogWrite(Buzzer, LOW);
      sleepmode = true;
      digitalWrite(MOSFED, LOW);
      display.clearDisplay();
      display.setTextSize(3);
      display.setTextColor(WHITE);
      display.setCursor(20, 4);
      display.print("SLEEP");
      display.display();
      delay(2000);
      both_pressed_count = 0;
    }
    both_pressed_count = both_pressed_count + 1;
  }

  if ((sleepmode || sleepmode_VibrSensor) && settings == 0) {
    digitalWrite(LED_R, HIGH);
    digitalWrite(LED_G, HIGH);
    digitalWrite(LED_B, HIGH);
    adc = 0;
    previousMillis_sleep = currentMillis;
    if (sleeplogo_count > 5000 && sleeplogo_count < 5005) {
      display.clearDisplay();
      display.drawBitmap(0, 0,  press_logo, 128, 32, 1);
      display.display();
    }
    if (sleeplogo_count > 10000 && sleeplogo_count < 10005) {
      display.clearDisplay();
      display.drawBitmap(0, 0,  no_press_logo, 128, 32, 1);
      display.display();
      sleeplogo_count = 0;
    }
    sleeplogo_count = sleeplogo_count + 1;
  }

  if (((currentMillis - previousMillis_sleep >= sleep_time_detect) && sleepmode_VibrSensor == false) && sleep_enabeled) {
    digitalWrite(LED_R, HIGH);
    digitalWrite(LED_G, HIGH);
    digitalWrite(LED_B, HIGH);
    sleepmode_VibrSensor = true;
    settings = 0;
    previousMillis_sleep = currentMillis;
    digitalWrite(MOSFED, LOW);
    display.clearDisplay();
    display.setTextSize(3);
    display.setTextColor(WHITE);
    display.setCursor(20, 4);
    display.print("SLEEP");
    display.display();
    analogWrite(Buzzer, 200);
    delay(70);
    analogWrite(Buzzer, LOW);
    delay(1000);
  }

  if (((digitalRead(ButtonL)) &&  sleepmode) && settings == 0) {
    digitalWrite(LED_R, HIGH);
    digitalWrite(LED_G, HIGH);
    digitalWrite(LED_B, HIGH);
    previousMillis_sleep = currentMillis;

    if (sleep_out_count > 800) {
      temp_change_count = 0;
      digitalWrite(MOSFED, LOW);
      analogWrite(Buzzer, 200);
      delay(70);
      analogWrite(Buzzer, LOW);
      settings = 1;
      sleep_out_count = 0;
      display.clearDisplay();
      display.setTextSize(1);
      display.setTextColor(WHITE);
      display.setCursor(21, 22);
      display.print("Set Sleep Time");
      display.display();
      delay(40);
      display.clearDisplay();
      display.setTextSize(1);
      display.setTextColor(WHITE);
      display.setCursor(21, 16);
      display.print("Set Sleep Time");
      display.display();
      delay(40);
      display.clearDisplay();
      display.setTextSize(1);
      display.setTextColor(WHITE);
      display.setCursor(21, 11);
      display.print("Set Sleep Time");
      display.display();
      delay(40);

    }
    sleep_out_count = sleep_out_count + 1;
  }

  if (!digitalRead(ButtonR)  &&  digitalRead(ButtonL) && settings == 1) {
    digitalWrite(LED_R, HIGH);
    digitalWrite(LED_G, HIGH);
    digitalWrite(LED_B, HIGH);
    previousMillis_sleep = currentMillis;

    if (sleep_out_count > 800) {
      temp_change_count = 0;
      digitalWrite(MOSFED, LOW);
      analogWrite(Buzzer, 200);
      delay(70);
      analogWrite(Buzzer, LOW);
      settings = 2;
      sleep_out_count = 0;
      slide_set_temp_down(sleeptime);
      delay(100);
    }
    sleep_out_count = sleep_out_count + 1;
  }

  if (digitalRead(ButtonR)  &&  !digitalRead(ButtonL) && settings == 1) {
    digitalWrite(LED_R, HIGH);
    digitalWrite(LED_G, HIGH);
    digitalWrite(LED_B, HIGH);
    previousMillis_sleep = currentMillis;

    if (sleep_out_count > 800) {
      temp_change_count = 0;
      digitalWrite(MOSFED, LOW);
      analogWrite(Buzzer, 200);
      delay(70);
      analogWrite(Buzzer, LOW);
      settings = 3;
      sleep_out_count = 0;
      display.clearDisplay();
      display.setTextSize(1);
      display.setTextColor(WHITE);
      display.setCursor(21, 22);
      display.print("Pre-set temp");
      display.display();
      delay(40);
      display.clearDisplay();
      display.setTextSize(1);
      display.setTextColor(WHITE);
      display.setCursor(21, 16);
      display.print("Pre-set temp");
      display.display();
      delay(40);
      display.clearDisplay();
      display.setTextSize(1);
      display.setTextColor(WHITE);
      display.setCursor(21, 11);
      display.print("Pre-set temp");
      display.display();
      delay(40);

    }
    sleep_out_count = sleep_out_count + 1;
  }

  if (digitalRead(ButtonR)  &&  !digitalRead(ButtonL) && settings == 3) {
    digitalWrite(LED_R, HIGH);
    digitalWrite(LED_G, HIGH);
    digitalWrite(LED_B, HIGH);
    previousMillis_sleep = currentMillis;
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

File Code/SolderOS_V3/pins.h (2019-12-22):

#ifndef PINS_H
#define PINS_H

//RGB LED on PCB//

#define LED_B 11 //PWM
#define LED_G 9  //PWM
#define LED_R 10 //PWM

//Buttons extern//

#define ButtonR    7 //no PWM
#define ButtonL    4 //no PWM

//IC2//

#define SDA A4
#define SCL A5

//Buzzer addable//

#define Buzzer 5 //PWM

//Voltage gauge//

#define VoltageGauge A2

//VibrSensor sensor//

#define VibrSensor A1

//Iron temp//

#define IronTemp A0

//MOSFED for soldering iron// 

#define MOSFED 3 //PWM

#endif

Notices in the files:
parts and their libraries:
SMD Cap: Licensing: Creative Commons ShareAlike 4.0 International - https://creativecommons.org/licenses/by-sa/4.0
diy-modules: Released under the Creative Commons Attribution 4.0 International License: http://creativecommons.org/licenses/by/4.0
